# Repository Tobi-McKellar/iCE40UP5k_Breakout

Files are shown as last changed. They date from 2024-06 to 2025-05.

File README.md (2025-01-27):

This is a simple FPGA breakout board based on the iCE40UP5K. Exposing 16 GPIO via two 6x1 PMOD ports and one 6x2 PMOD port, as well as 11 LEDs, 3 buttons, and one capacitive touch button, the board can be powered via USB-C or the appropriate mounting holes. Programmed via [SOIC-Bite](https://github.com/SimonMerrett/SOICbite/blob/master/README.md). The schematic and PCB can be viewed online [here](https://kicanvas.org/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) via KiCanvas.

Screenshot 2025-01-28 at 12 22 27 AM



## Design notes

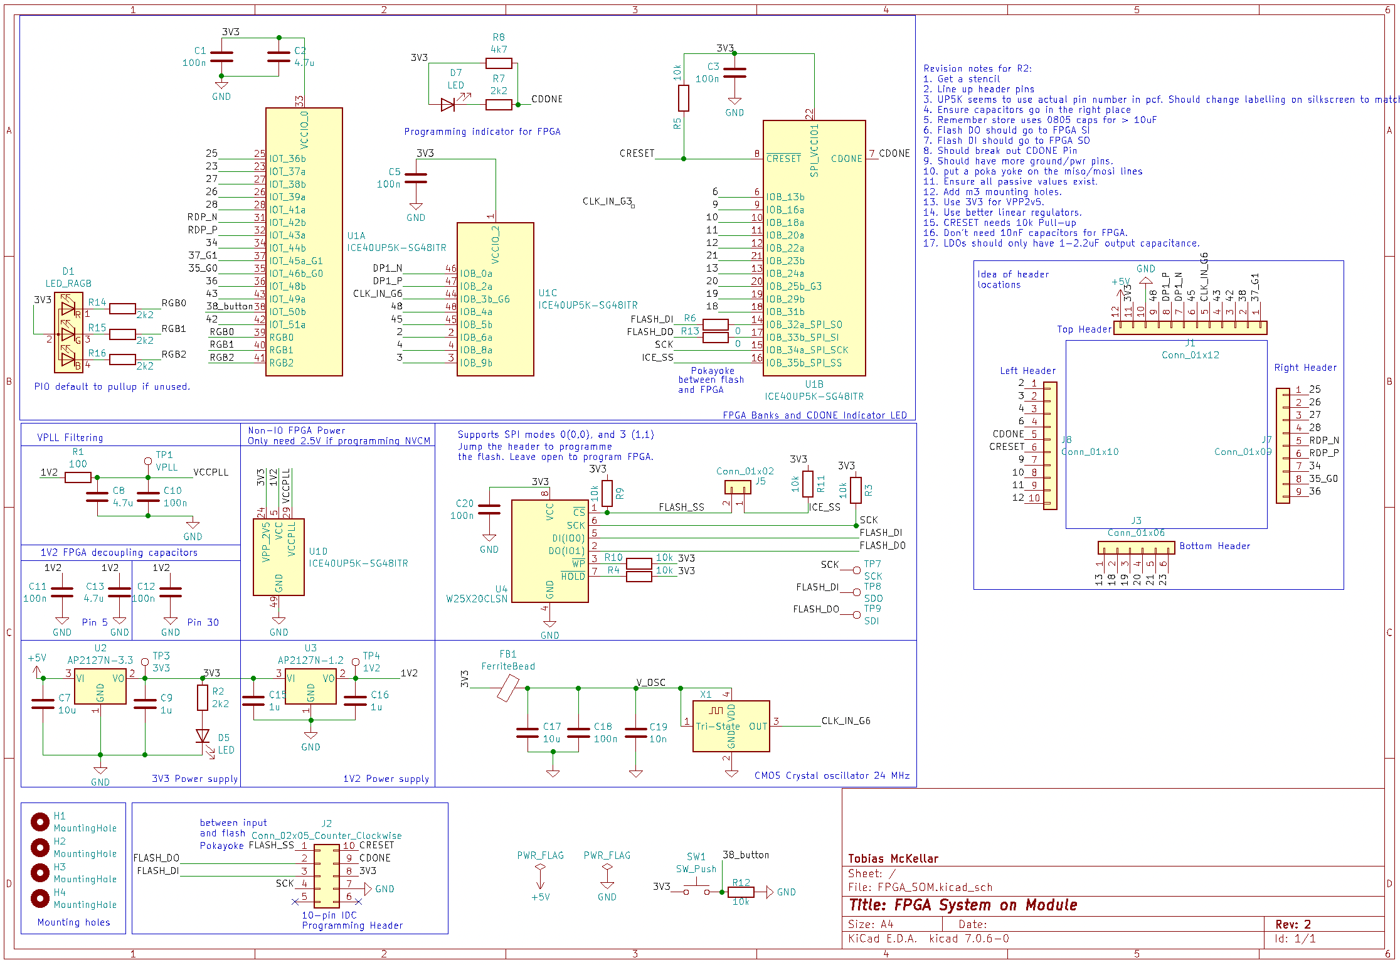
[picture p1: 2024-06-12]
FPGA_SOM/schematic.png

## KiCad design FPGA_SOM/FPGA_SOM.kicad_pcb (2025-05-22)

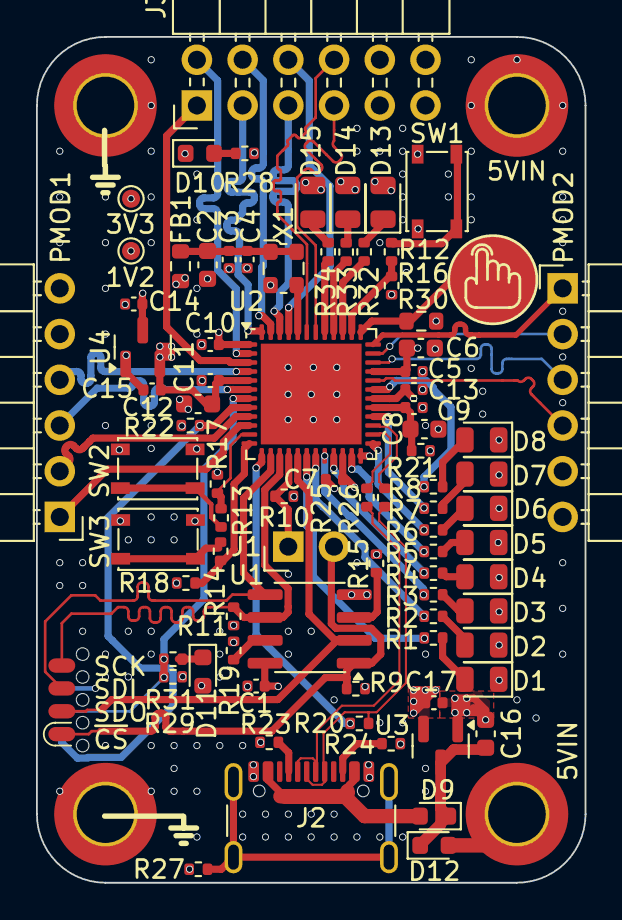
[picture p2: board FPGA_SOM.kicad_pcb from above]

Board: 6 copper layers, 30.5 x 47.0 mm, 88 parts (0 on the bottom side), 73 nets.

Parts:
C1, C3, C5, C7, C9, C10, C11, C13: 100n; C_0402_1005Metric
C2, C16: 10u; C_0603_1608Metric
C4: 10n; C_0402_1005Metric
C6, C8, C12: 4.7u; C_0603_1608Metric
C14, C15, C17: 1u; C_0402_1005Metric
D1, D2, D14: GLED; LED_0805_2012Metric
D3, D4, D15: BLED; LED_0805_2012Metric
D5, D6: YLED; LED_0805_2012Metric
D7, D8, D13: RLED; LED_0805_2012Metric
D9, D12: D_Schottky; D_0603_1608Metric
D10, D11: LED; D_0603_1608Metric
FB1: FerriteBead; R_0603_1608Metric
H1, H2, H3, H4: MountingHole_Pad; MountingHole_3.2mm_M3_ISO7380_Pad_TopBottom
J1: Conn_01x02; PinHeader_1x02_P2.54mm_Vertical
J2: USB_C_Receptacle_USB2.0; USB_C_Receptacle_GCT_USB4105-xx-A_16P_TopMnt_Horizontal
J3: Conn_02x06_Top_Bottom; PinHeader_2x06_P2.54mm_Horizontal
J4: Conn_02x04_Counter_Clockwise; SOIC_clipProgSmall
J5, J6: Conn_01x06; PinHeader_1x06_P2.54mm_Horizontal
R1, R2, R3, R4, R5, R6: 470; R_0402_1005Metric
R7, R8, R12, R13, R14: 1k; R_0402_1005Metric
R9, R10, R11, R15, R16, R17, R18, R19, R22: 10k; R_0402_1005Metric
R20: 1k5; R_0402_1005Metric
R21: 100; R_0402_1005Metric
R23, R24: 5k1; R_0402_1005Metric
R25, R26: 22; R_0402_1005Metric
R27: 0; R_0402_1005Metric
R28, R31, R32, R33, R34: 2k2; R_0402_1005Metric
R29: 4k7; R_0402_1005Metric
R30: 1M; R_0603_1608Metric
SW1, SW2, SW3: SW_Push; SW_SPST_PTS810
TP1: 3V3; TestPoint_Pad_D1.0mm
TP2: 1V2; TestPoint_Pad_D1.0mm
U1: W25Q128JVSIQ; SOIC-8_3.9x4.9mm_P1.27mm
U2: ICE40UP5K-SG48ITR; QFN-48-1EP_7x7mm_P0.5mm_EP5.6x5.6mm
U3: AP2127N-3.3; SOT-23
U4: AP2127N-1.2; SOT-23
U5: Capacitive_touchpad
X1: SX2M36.000B10F20TNN; Oscillator_SMD_ECS_2520MV-xxx-xx-4Pin_2.5x2.0mm

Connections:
+5V: C16.2, D9.1 (K), D12.1 (K), U3.3 (VI)
/1V2: C11.1, C12.1, C13.1, C15.1, R21.2, TP2.1, U2.5 (VCC), U2.30 (VCC), U4.2 (VO)
/3V3: C1.1, C5.1, C6.1, C7.1, C10.1, C14.2, C17.1, D11.2 (A), D13.2 (A), D14.2 (A), D15.2 (A), FB1.1, J3.11, J3.12, J5.6, J6.6, R9.1, R10.1, R11.1, R15.1, R19.1, R22.1, R28.1, R29.1, R30.1, SW1.1, SW2.1, SW3.1, TP1.1, U1.8 (VCC), U2.1 (VCCIO_2), U2.22 (SPI_VCCIO1), U2.24 (VPP_2V5), U2.33 (VCCIO_0), U3.2 (VO), U4.3 (VI)
/31_button: R12.1, R16.2, U2.38 (IOT_50b)
/BLED0: R3.2, U2.20 (IOB_25b_G3)
/BLED1: R4.2, U2.21 (IOB_23b)
/Button_2: R13.1, R17.2, U2.11 (IOB_20a)
/Button_6: R14.1, R18.2, U2.12 (IOB_22a)
/CDONE: J4.7, R29.2, R31.1, U2.7 (CDONE)
/CLK_IN_G6: U2.44 (IOB_3b_G6), X1.3 (OUT)
/CRESET: J4.8, R22.2, U2.8 (~CRESET)
/Cap_touch: R30.2, U2.37 (IOT_45a_G1), U5.1 (Sense)
/D_N: R25.2, U2.26 (IOT_39a)
/D_P: R26.2, U2.27 (IOT_38b)
/Din_N: J2.A7 (D-), J2.B7 (D-), R25.1
/Din_P: J2.A6 (D+), J2.B6 (D+), R20.1, R26.1
/FLASH_DI: J4.3, U1.5 (DI(IO0)), U2.14 (IOB_32a_SPI_SO)
/FLASH_DO: J4.2, U1.2 (DO(IO1)), U2.17 (IOB_33b_SPI_SI)
/FLASH_SS: J1.2, J4.1, R9.2, U1.1 (~CS)
/GLED0: R1.2, U2.18 (IOB_31b)
/GLED1: R2.2, U2.19 (IOB_29b)
/ICE_SS: J1.1, R10.2, U2.16 (IOB_35b_SPI_SS)
/PMOD1_25: J5.4, U2.4 (IOB_8a)
/PMOD1_26: J5.2, U2.9 (IOB_16a)
/PMOD1_27: J5.3, U2.6 (IOB_13b)
/PMOD1_28: J5.1, U2.10 (IOB_18a)
/PMOD2_45: J3.4, U2.47 (IOB_2a)
/PMOD2_46: J3.3, U2.48 (IOB_4a)
/PMOD2_47: J3.2, U2.2 (IOB_6a)
/PMOD2_48: J3.1, U2.3 (IOB_9b)
/PMOD3_32: J6.4, U2.32 (IOT_43a)
/PMOD3_34: J6.3, U2.34 (IOT_44b)
/PMOD3_35_G0: J6.2, U2.35 (IOT_46b_G0)
/PMOD3_36: J6.1, U2.36 (IOT_48b)
/PMOD3_37_G1: J3.8, U2.43 (IOT_49a)
/PMOD3_38: J3.7, U2.42 (IOT_51a)
/PMOD3_42: J3.6, U2.45 (IOB_5b)
/PMOD3_43: J3.5, U2.46 (IOB_0a)
/RGB0: R32.1, U2.39 (RGB0)
/RGB1: R33.1, U2.40 (RGB1)
/RGB2: R34.1, U2.41 (RGB2)
/RLED0: R7.2, U2.28 (IOT_41a)
/RLED1: R8.2, U2.31 (IOT_42b)
/SCK: J4.4, R11.2, U1.6 (SCK), U2.15 (IOB_34a_SPI_SCK)
/USB_Detect: R20.2, U2.13 (IOB_24a)
/VCCPLL: C8.1, C9.1, R21.1, U2.29 (VCCPLL)
/V_OSC: C2.1, C3.1, C4.2, FB1.2, X1.1 (Tri-State), X1.4 (VDD)
/YLED0: R5.2, U2.23 (IOT_37a)
/YLED1: R6.2, U2.25 (IOT_36b)
GND: C1.2, C2.2, C3.2, C4.1, C5.2, C6.2, C7.2, C8.2, C9.2, C10.2, C11.2, C12.2, C13.2, C14.1, C15.2, C16.1, C17.2, D1.1 (K), D2.1 (K), D3.1 (K), D4.1 (K), D5.1 (K), D6.1 (K), D7.1 (K), D8.1 (K), D10.1 (K), H3.1, H4.1, J2.A1 (GND), J2.A12 (GND), J2.B1 (GND), J2.B12 (GND), J3.9, J3.10, J4.6, J5.5, J6.5, R16.1, R17.1, R18.1, R23.2, R24.2, R27.2, U1.4 (GND), U2.49 (GND), U3.1 (GND), U4.1 (GND), X1.2 (GND)
unnamed: D1.2 (A), R1.1
unnamed: D2.2 (A), R2.1
unnamed: D3.2 (A), R3.1
unnamed: D4.2 (A), R4.1
unnamed: D5.2 (A), R5.1
unnamed: D6.2 (A), R6.1
unnamed: D7.2 (A), R7.1
unnamed: D8.2 (A), R8.1
unnamed: D9.2 (A), J2.A4 (VBUS), J2.A9 (VBUS), J2.B4 (VBUS), J2.B9 (VBUS)
unnamed: D10.2 (A), R28.2
unnamed: D11.1 (K), R31.2
unnamed: D12.2 (A), H1.1, H2.1
unnamed: D13.1 (K), R32.2
unnamed: D14.1 (K), R33.2
unnamed: D15.1 (K), R34.2
unnamed: J2.A5 (CC1), R23.1
unnamed: J2.B5 (CC2), R24.1
unnamed: J2.S1 (SHIELD), R27.1
unnamed: R12.2, SW1.2
unnamed: R13.2, SW2.2
unnamed: R14.2, SW3.2
unnamed: R19.2, U1.7 (~HOLD)
unnamed: R15.2, U1.3 (~WP)

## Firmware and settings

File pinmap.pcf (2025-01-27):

# Clock
set_io clk 44
set_frequency clk 24.0

# Normal LEDs
set_io -nowarn YLED0 23
set_io -nowarn YLED1 25
set_io -nowarn RLED0 28
set_io -nowarn RLED1 31
set_io -nowarn GLED0 18
set_io -nowarn GLED1 19
set_io -nowarn BLED0 20
set_io -nowarn BLED1 21

# RGB LEDs
set_io -nowarn RGB_R 39
set_io -nowarn RGB_G 40
set_io -nowarn RGB_B 41

# Pushbuttons
set_io -nowarn pattern[0] 38
set_io -nowarn pattern[1] 11
set_io -nowarn pattern[2] 12

# Capacitive touch button
set_io -nowarn pattern[3] 37

# PMODs

# 3V3 GND 3 2 1 0
# 3V3 GND 7 6 5 4

# PMOD1
set_io -nowarn PMOD1_3 4
set_io -nowarn PMOD1_2 6
set_io -nowarn PMOD1_1 9
set_io -nowarn PMOD1_0 10

# PMOD2
set_io -nowarn PMOD2_3 32
set_io -nowarn PMOD2_2 34
set_io -nowarn PMOD2_1 35
set_io -nowarn PMOD2_0 36

# PMOD3
set_io -nowarn PMOD3_7 43
set_io -nowarn PMOD3_6 45
set_io -nowarn PMOD3_5 47
set_io -nowarn PMOD3_4 2
set_io -nowarn PMOD3_3 42
set_io -nowarn PMOD3_2 46
set_io -nowarn PMOD3_1 48
set_io -nowarn PMOD3_0 3

# USB
set_io -nowarn USB_DP 27
set_io -nowarn USB_DN 26
set_io -nowarn USB_PULLUP 13

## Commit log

2024-04-17 First commit.
    [FPGA_SOM.kicad_pcb, FPGA_SOM.kicad_sch]
2024-05-04 Version one. Had some errors documented in schematic which I will fix in version 2.
    [FPGA_SOM.kicad_sch]
2024-05-04 First attempt at V2. Likely to be changed in the near future.
    [FPGA_SOM.kicad_pcb, FPGA_SOM.kicad_sch]
2024-05-04 Added JLC text and my name. to silkscreen.
    [FPGA_SOM.kicad_pcb]
2024-05-06 add pullup resistor to sck on schematic.
    [FPGA_SOM.kicad_sch]
2024-05-15 Saving progress.
    [FPGA_SOM.kicad_pcb, FPGA_SOM.kicad_sch]
2024-05-17 Remove some unnecessary capacitors and resize others.
    [FPGA_SOM.kicad_pcb, FPGA_SOM.kicad_sch]
2024-05-17 Add png of schematic for V2.
2024-05-18 Added silkscreen and removed unneded test points.
    [FPGA_SOM.kicad_pcb, FPGA_SOM.kicad_sch]
2024-05-18 ficing small things and adding qr code to repo.
    [FPGA_SOM.kicad_pcb]
2024-05-18 Added button and clarified silkscreen for RGB leds.
    [FPGA_SOM.kicad_pcb, FPGA_SOM.kicad_sch]
2024-05-31 Added silkscreen, stitching vias, and quality of life improvements.
    [FPGA_SOM.kicad_pcb, FPGA_SOM.kicad_sch]
2024-06-12 QOL changes before production.
    [FPGA_SOM.kicad_pcb, FPGA_SOM.kicad_sch]
2024-06-12 Added notes to schematic.
    [FPGA_SOM.kicad_sch]
2024-06-12 Add new schematic.
2024-06-12 Rename Screen Shot 2024-06-13 at 12.31.32 AM.png to schematic.png
2024-06-23 Added ethernet, usb-c, capacitive touch button, and PMOD to schematic. Started PCB layout for V3.
    [FPGA_SOM.kicad_pcb, FPGA_SOM.kicad_sch]
2024-12-23 V3. New form factor, many improvements.
    [FPGA_SOM.kicad_pcb, FPGA_SOM.kicad_sch]
2024-12-28 Final version 3 sent for assembly.
    [FPGA_SOM.kicad_pcb, FPGA_SOM.kicad_sch]
2025-05-22 Kicad Update changes some things. Also reorganise nets.
    [FPGA_SOM.kicad_pcb, FPGA_SOM.kicad_sch]
